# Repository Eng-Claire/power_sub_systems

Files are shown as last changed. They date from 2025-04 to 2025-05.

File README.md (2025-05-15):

Welcome to the MicroMouse project kiCAD files of Chidochashe Kufakunesu ( KFKCHI001) and Danella Oelofse ( OLFDAN001 )

The folder titled 'FinalMicroMouseFiles' is the final version of our project and the version that was submitted to UCT. It includes a screenshot of the JLCPCB cart, the BOM, the positions file, as well as the gerber and drill files from kiCAD.

The zip folder is the kiCAD gerber files that were submitted to JLCPCB for manufacturing.

The pdf entitled 'FinalSchematic' is the schematic of our entire solution for the power subsystem.

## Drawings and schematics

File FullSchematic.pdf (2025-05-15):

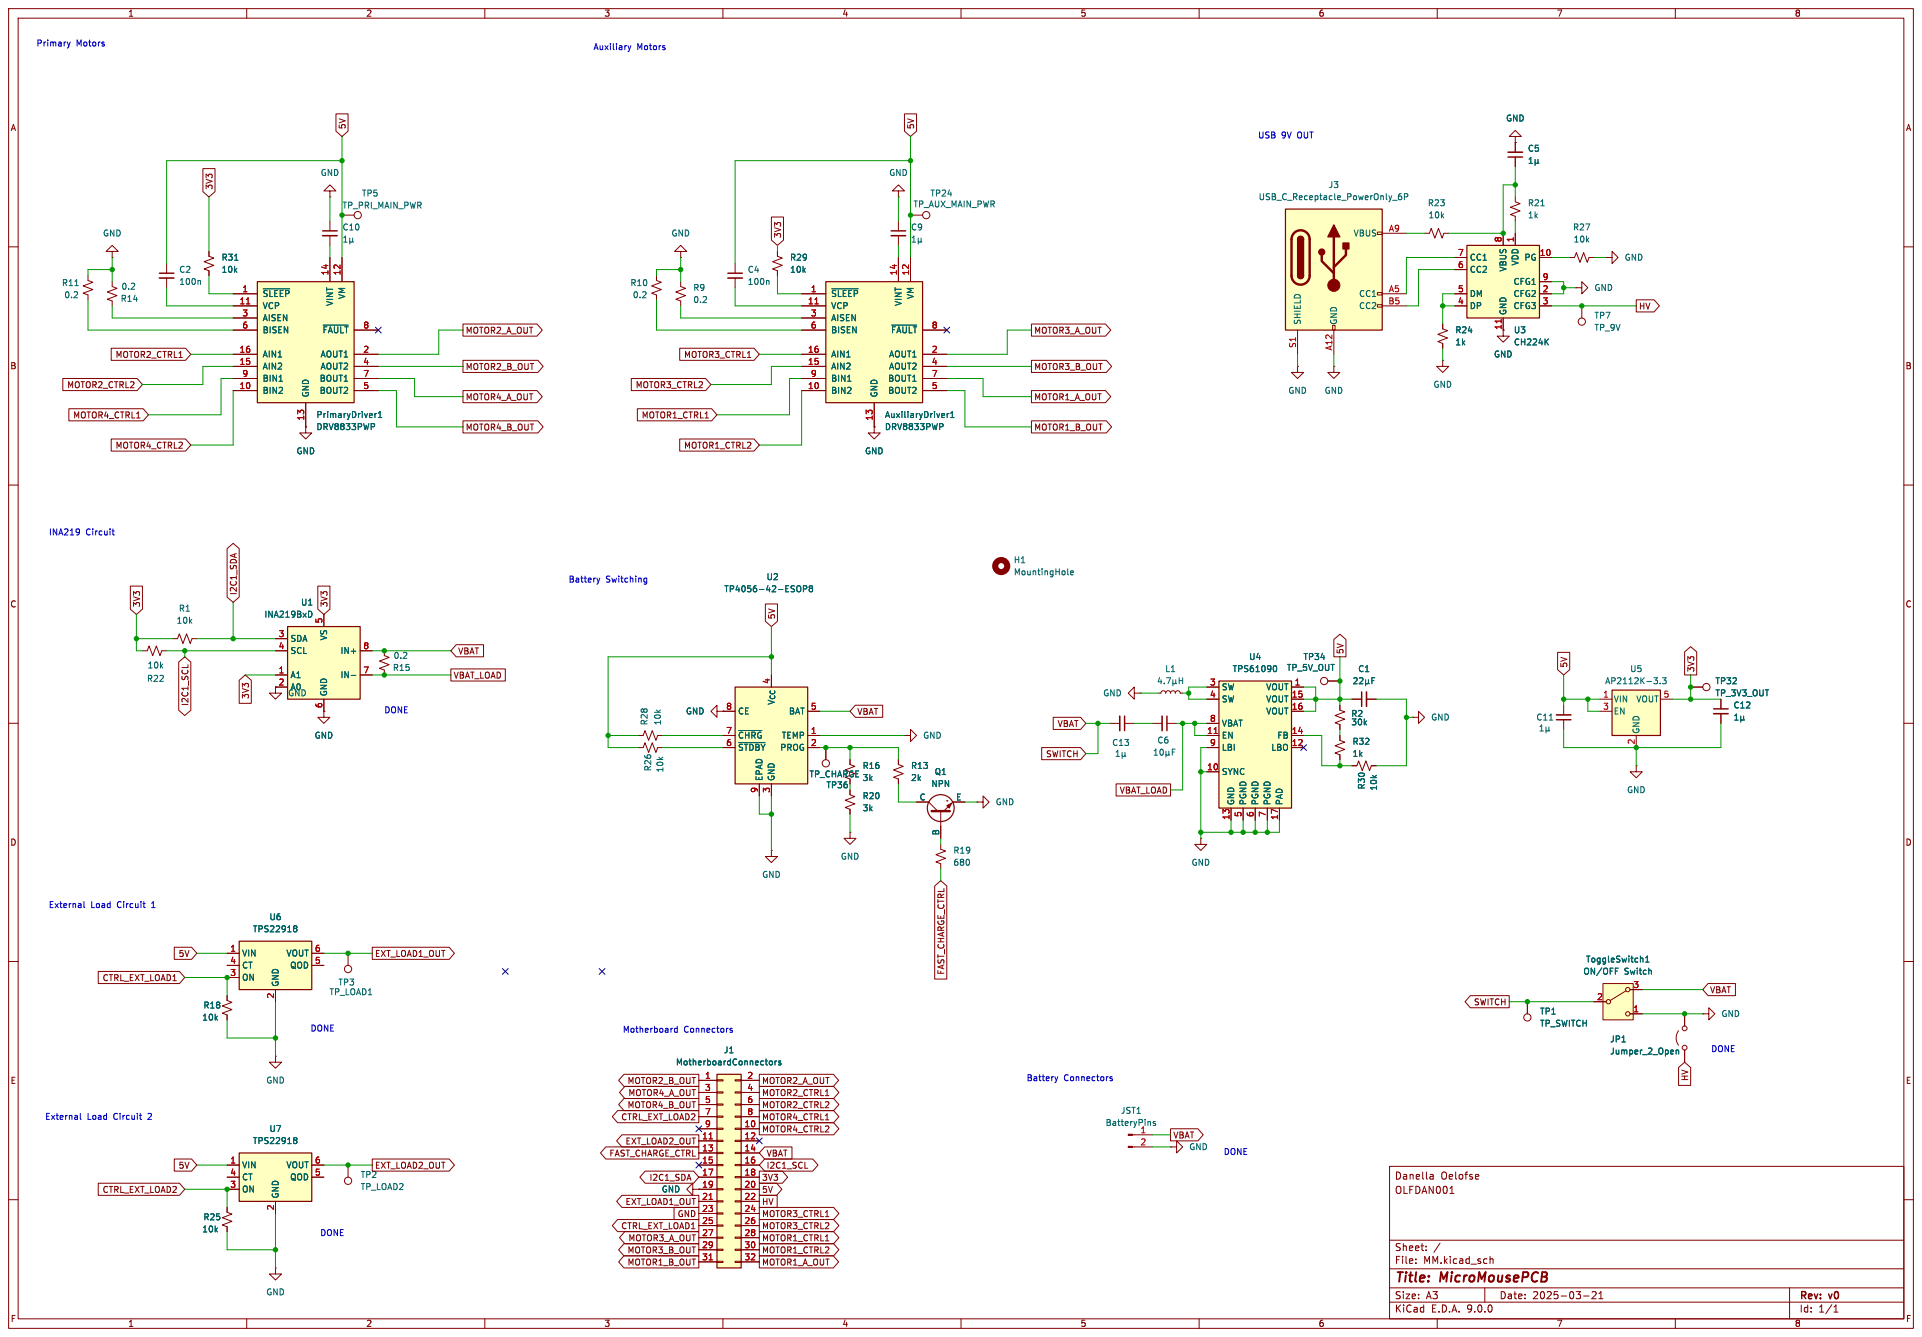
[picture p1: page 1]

2 VOUT 6 QOD 5 U7 TPS22918 SHIELD S1 GND A12 VBUS A9 CC1 A5 CC2 B5

6 SDA 3 SCL 4 A1 1 A0 2 GND GND

U4 TPS61090 SW 3 SW 4 VBAT 8 EN 11

SW 3 SW 4 VBAT 8 EN 11

7 PAD 17 VOUT 1 VOUT 15 VOUT 16 FB 14

3 BAT 5 TEMP 1 PROG 2 Q1 NPN

2 VOUT 6 QOD 5 U6 TPS22918 VIN 1 CT 4 ON 3 GND

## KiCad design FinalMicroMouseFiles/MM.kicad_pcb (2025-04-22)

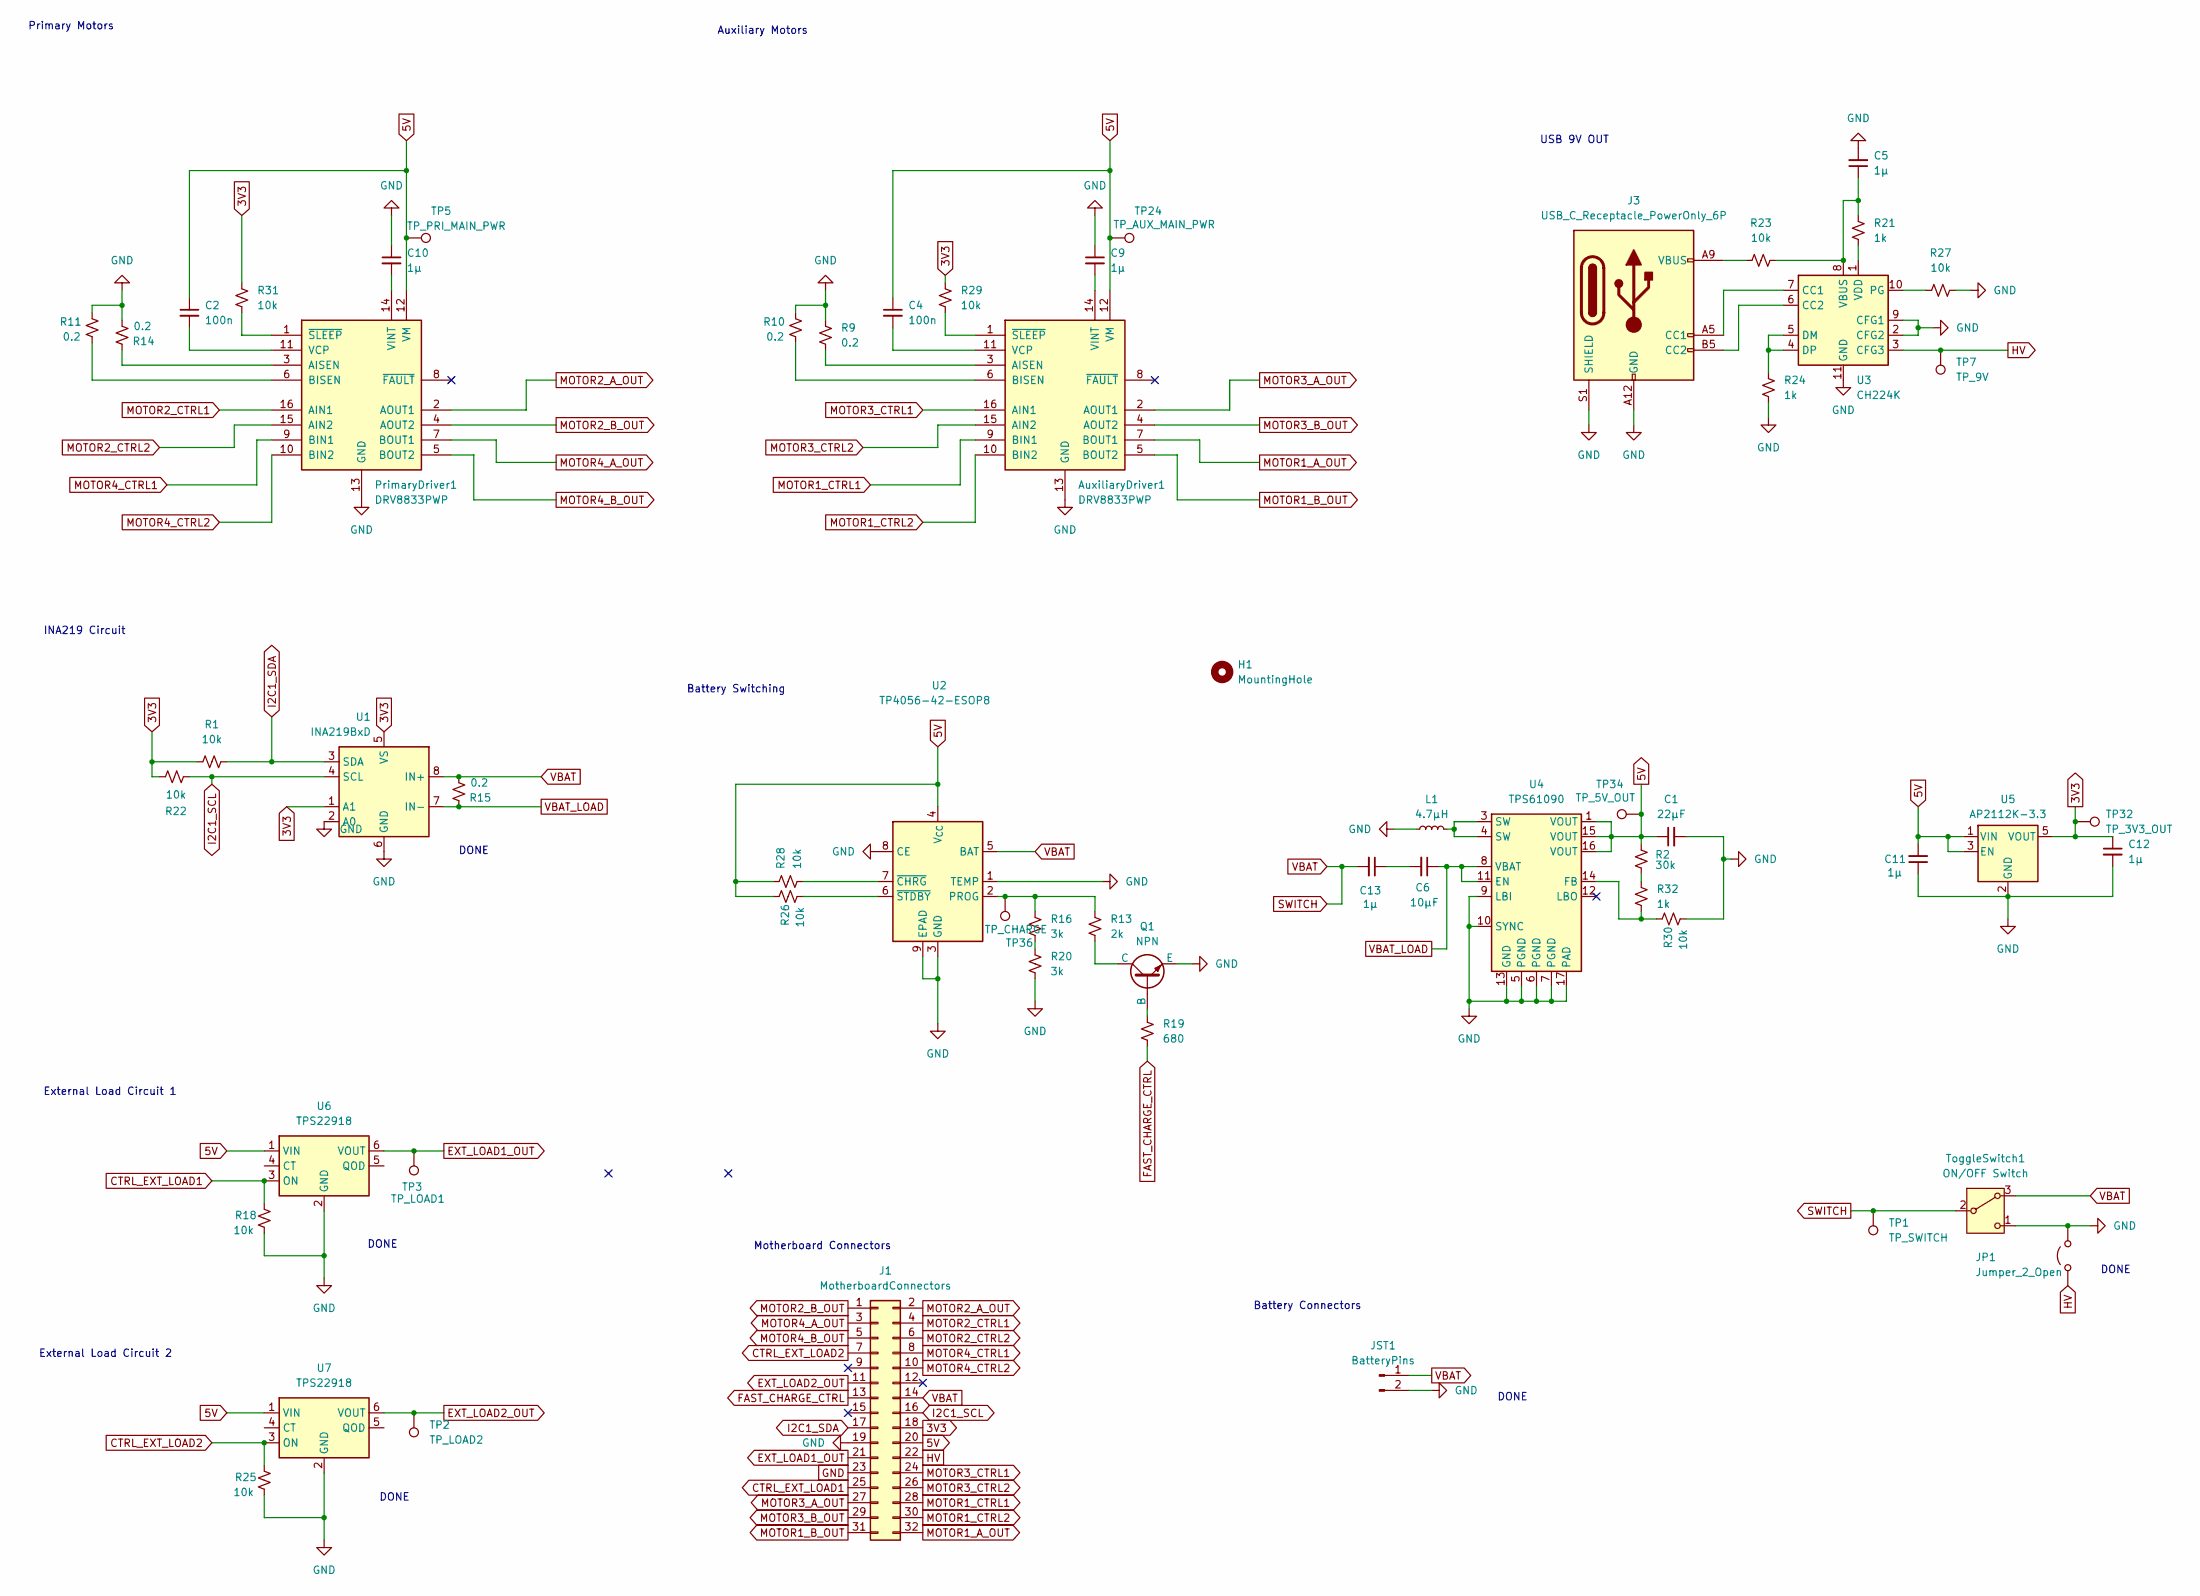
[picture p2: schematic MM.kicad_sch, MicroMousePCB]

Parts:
AuxiliaryDriver1: DRV8833PWP; TSSOP-16-1EP_4.4x5mm_P0.65mm_EP3x3mm_ThermalVias; LCSC C50506
C1: 22µF; C_0805_2012Metric_Pad1.18x1.45mm_HandSolder; LCSC C45783
C2, C4: 100n; C_0402_1005Metric; LCSC C1525
C5, C9, C10, C11, C12, C13: 1μ; C_0504_1310Metric_Pad0.83x1.28mm_HandSolder; LCSC C15849
C6: 10µF; C_1206_3216Metric_Pad1.33x1.80mm_HandSolder; LCSC C13585
H1: MountingHole; MountingHole_3.2mm_M3_DIN965_Pad
J1: MotherboardConnectors; PinHeader_2x16_P2.54mm_Vertical
J3: USB_C_Receptacle_PowerOnly_6P; USB_C_Receptacle_GCT_USB4125-xx-x-0190_6P_TopMnt_Horizontal; LCSC C668623
JP1: Jumper_2_Open; TestPoint_2Pads_Pitch2.54mm_Drill0.8mm
JST1: BatteryPins; JST_PH_B2B-PH-K_1x02_P2.00mm_Vertical; LCSC C157955
L1: 4.7µH; L_0603_1608Metric_Pad1.05x0.95mm_HandSolder; LCSC C114862
PrimaryDriver1: DRV8833PWP; TSSOP-16-1EP_4.4x5mm_P0.65mm_EP3x3mm_ThermalVias; LCSC C50506
Q1: NPN; TO-92; LCSC C5330385
R1, R18, R22, R23, R25, R26, R27, R28, R29, R30, R31: 10k; R_0805_2012Metric_Pad1.20x1.40mm_HandSolder; LCSC C17414
R2: 30k; R_0603_1608Metric_Pad0.98x0.95mm_HandSolder; LCSC C22984
R9, R10, R11, R14, R15: 0.2; R_0805_2012Metric; LCSC C2934262
R13: 2k; R_0603_1608Metric_Pad0.98x0.95mm_HandSolder; LCSC C22975
R16, R20: 3k; R_0603_1608Metric_Pad0.98x0.95mm_HandSolder; LCSC C4211
R19: 680; R_0603_1608Metric_Pad0.98x0.95mm_HandSolder; LCSC C23228
R21, R24, R32: 1k; R_0402_1005Metric; LCSC C11702
TP1: TP_SWITCH; TestPoint_Pad_D2.0mm
TP2: TP_LOAD2; TestPoint_Pad_D2.0mm
TP3: TP_LOAD1; TestPoint_Pad_D2.0mm
TP5: TP_PRI_MAIN_PWR; TestPoint_Pad_D2.0mm
TP7: TP_9V; TestPoint_Pad_D2.0mm
TP24: TP_AUX_MAIN_PWR; TestPoint_Pad_D2.0mm
TP32: TP_3V3_OUT; TestPoint_Pad_D2.0mm
TP34: TP_5V_OUT; TestPoint_Pad_D2.0mm
TP36: TP_CHARGE; TestPoint_Pad_D2.0mm
ToggleSwitch1: ON/OFF Switch; SW_SPDT_CK_JS102011SAQN; LCSC C1788492
U1: INA219BxD; SOIC-8-1EP_3.9x4.9mm_P1.27mm_EP2.29x3mm; LCSC C138706
U2: TP4056-42-ESOP8; SOIC-8-1EP_3.9x4.9mm_P1.27mm_EP2.41x3.3mm_ThermalVias; LCSC C16581
U3: CH224K; SSOP-10-1EP_3.9x4.9mm_P1mm_EP2.1x3.3mm; LCSC C970725
U4: TPS61090; Texas_RSA_VQFN-16-1EP_4x4mm_P0.65mm_EP2.7x2.7mm_ThermalVias; LCSC C206167
U5: AP2112K-3.3; SOT-23-5; LCSC C3021085
U6, U7: TPS22918; SOT-23-6; LCSC C131941

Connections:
3V3: C12.1, J1.18, R1.1, R22.2, R29.1, R31.1, TP32.1, U1.1 (A1), U1.5 (VS), U5.5 (VOUT)
5V: AuxiliaryDriver1.12 (VM), C1.1, C2.1, C4.1, C11.2, J1.20, PrimaryDriver1.12 (VM), R2.1, R26.1, R28.1, TP5.1, TP24.1, TP34.1, U2.4 (V_{CC}), U4.1 (VOUT), U4.15 (VOUT), U4.16 (VOUT), U5.1 (VIN), U5.3 (EN), U6.1 (VIN), U7.1 (VIN)
CTRL_EXT_LOAD1: J1.25, R18.1, U6.3 (ON)
CTRL_EXT_LOAD2: J1.7, R25.1, U7.3 (ON)
EXT_LOAD1_OUT: J1.21, TP3.1, U6.6 (VOUT)
EXT_LOAD2_OUT: J1.11, TP2.1, U7.6 (VOUT)
FAST_CHARGE_CTRL: J1.13, R19.2
GND: AuxiliaryDriver1.13 (GND), AuxiliaryDriver1.17 (GND), C1.2, C5.2, C9.1, C10.1, C11.1, C12.2, J1.19, J1.23, J3.A12 (GND), J3.B12 (GND), J3.S1 (SHIELD), JP1.2 (B), JST1.2, L1.1, PrimaryDriver1.13 (GND), PrimaryDriver1.17 (GND), Q1.3 (E), R9.2, R10.2, R11.2, R14.1, R18.2, R20.2, R24.2, R25.2, R27.2, R30.2, ToggleSwitch1.1 (C), U1.2 (A0), U1.6 (GND), U2.1 (TEMP), U2.3 (GND), U2.8 (CE), U2.9 (EPAD), U3.2 (CFG2), U3.9 (CFG1), U3.11 (GND), U4.5 (PGND), U4.6 (PGND), U4.7 (PGND), U4.9 (LBI), U4.10 (SYNC), U4.13 (GND), U4.17 (PAD), U5.2 (GND), U6.2 (GND), U7.2 (GND)
HV: J1.22, JP1.1 (A), TP7.1, U3.3 (CFG3)
I2C1_SCL: J1.16, R22.1, U1.4 (SCL)
I2C1_SDA: J1.17, R1.2, U1.3 (SDA)
MOTOR1_A_OUT: AuxiliaryDriver1.7 (BOUT1), J1.32
MOTOR1_B_OUT: AuxiliaryDriver1.5 (BOUT2), J1.31
MOTOR1_CTRL1: AuxiliaryDriver1.9 (BIN1), J1.28
MOTOR1_CTRL2: AuxiliaryDriver1.10 (BIN2), J1.30
MOTOR2_A_OUT: J1.2, PrimaryDriver1.2 (AOUT1)
MOTOR2_B_OUT: J1.1, PrimaryDriver1.4 (AOUT2)
MOTOR2_CTRL1: J1.4, PrimaryDriver1.16 (AIN1)
MOTOR2_CTRL2: J1.6, PrimaryDriver1.15 (AIN2)
MOTOR3_A_OUT: AuxiliaryDriver1.2 (AOUT1), J1.27
MOTOR3_B_OUT: AuxiliaryDriver1.4 (AOUT2), J1.29
MOTOR3_CTRL1: AuxiliaryDriver1.16 (AIN1), J1.24
MOTOR3_CTRL2: AuxiliaryDriver1.15 (AIN2), J1.26
MOTOR4_A_OUT: J1.3, PrimaryDriver1.7 (BOUT1)
MOTOR4_B_OUT: J1.5, PrimaryDriver1.5 (BOUT2)
MOTOR4_CTRL1: J1.8, PrimaryDriver1.9 (BIN1)
MOTOR4_CTRL2: J1.10, PrimaryDriver1.10 (BIN2)
unnamed: AuxiliaryDriver1.3 (AISEN), R9.1
unnamed: AuxiliaryDriver1.6 (BISEN), R10.1
unnamed: AuxiliaryDriver1.11 (VCP), C4.2
unnamed: AuxiliaryDriver1.14 (VINT), C9.2
unnamed: AuxiliaryDriver1.1 (~SLEEP), R29.2
unnamed: C6.2, C13.1
unnamed: J3.A5 (CC1), U3.7 (CC1)
unnamed: J3.B5 (CC2), U3.6 (CC2)
unnamed: J3.A9 (VBUS), J3.B9 (VBUS), R23.1
unnamed: L1.2, U4.3 (SW), U4.4 (SW)
unnamed: PrimaryDriver1.3 (AISEN), R14.2
unnamed: PrimaryDriver1.6 (BISEN), R11.1
unnamed: C2.2, PrimaryDriver1.11 (VCP)
unnamed: C10.2, PrimaryDriver1.14 (VINT)
unnamed: PrimaryDriver1.1 (~SLEEP), R31.2
unnamed: Q1.2 (B), R19.1
unnamed: Q1.1 (C), R13.2
unnamed: R2.2, R32.1
unnamed: R16.2, R20.1
unnamed: R13.1, R16.1, TP36.1, U2.2 (PROG)
unnamed: R28.2, U2.7 (~CHRG)
unnamed: R26.2, U2.6 (~STDBY)
unnamed: R24.1, U3.4 (DP), U3.5 (DM)
unnamed: R27.1, U3.10 (PG)
unnamed: C5.1, R21.1, R23.2, U3.8 (VBUS)
unnamed: R21.2, U3.1 (VDD)
unnamed: R30.1, R32.2, U4.14 (FB)
SWITCH: C13.2, J1.14, JST1.1, R15.1, TP1.1, ToggleSwitch1.2 (B), ToggleSwitch1.3 (A), U1.8 (IN+), U2.5 (BAT)
VBAT_LOAD: C6.1, R15.2, U1.7 (IN-), U4.8 (VBAT), U4.11 (EN)

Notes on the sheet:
Primary Motors
DONE
External Load Circuit 1
Motherboard Connectors
INA219 Circuit
Battery Connectors
Auxiliary Motors
External Load Circuit 2
USB 9V OUT
Battery Switching

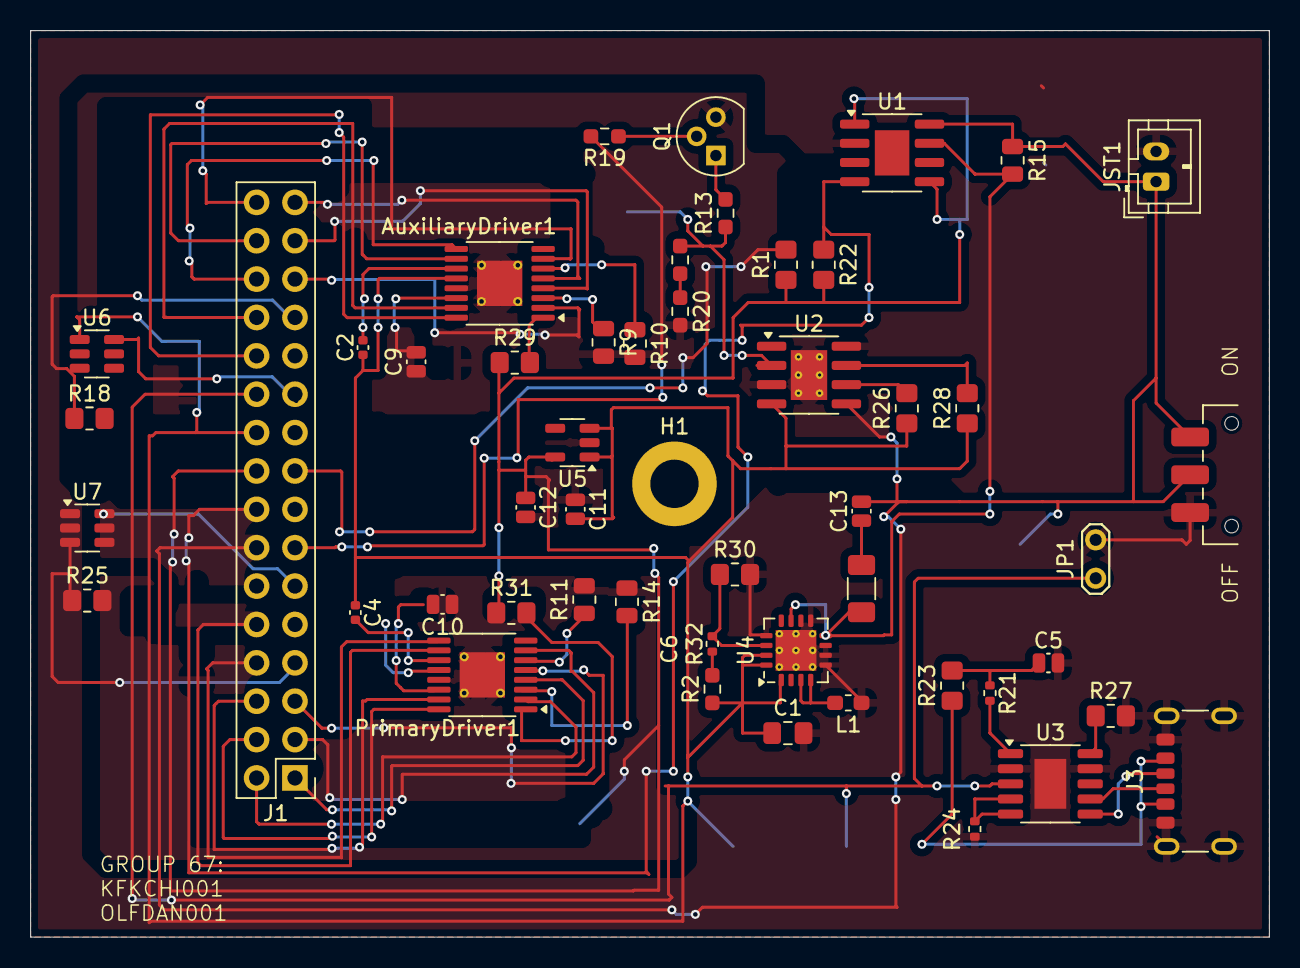
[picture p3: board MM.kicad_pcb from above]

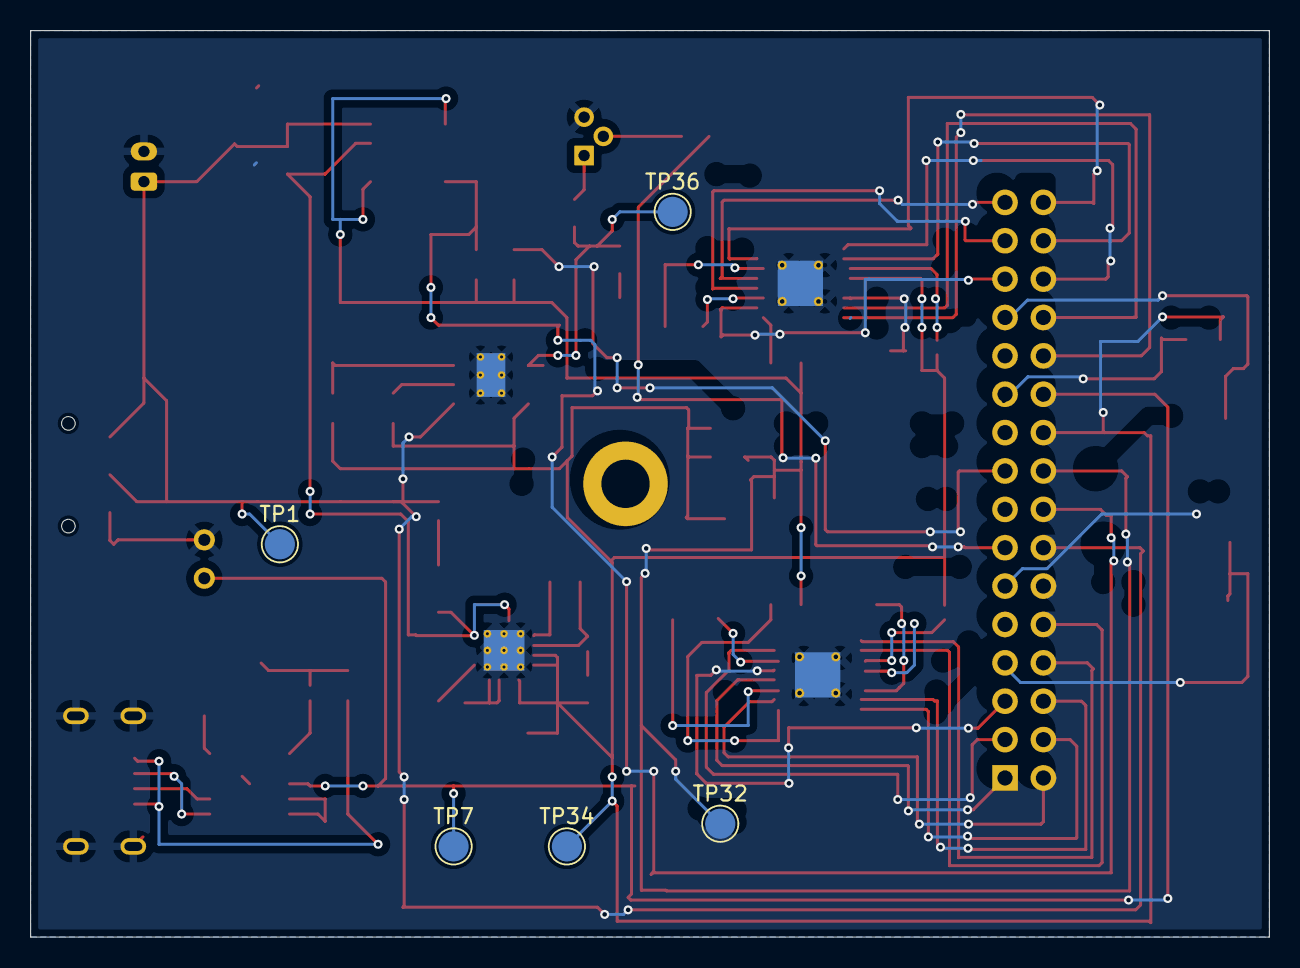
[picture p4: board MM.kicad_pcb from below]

Board: 2 copper layers, 82.0 x 60.0 mm, 56 parts (5 on the bottom side), 56 nets.
